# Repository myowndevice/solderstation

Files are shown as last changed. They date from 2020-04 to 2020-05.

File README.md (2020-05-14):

## Цифровая паяльная станция

Паяльная станция - специальный прибор для автоматической регулировки температуры жала обычного паяльника на 220в или для управления паяльным термофеном.
Полностью цифровой вариант.
Для измерения термопары используется самый современный метод - внешний 18-ти битный сигма-дельта ADC. Для управления вентилятором фена - ШИМ модуляция и MOSFET. PID регулятор температуры с возможностью различных настроек для фена и паяльника.

Ключевые особенности самодельной паяльной станции:
- Компактный размер
- Встроенный блок питания на 220В
- Возможность определения вида нагревателя (2 прибора, паяльник и фен)
- Цифровая регулировка мощности нагревателя на основе PID регулятора
- Возможность управления паяльником постоянного напряжения до 24В
- Возможность управления вентилятором термофена (4 скорости)
- Управление нагрузкой целыми полуволнами, с учётом перехода через 0 (меньше помех)
- Защита от перегрева нагревателя
- Индикатор температуры и скорости вентилятора
- Управление тактовыми кнопками
- Защита от ложных срабатываний управляющего симистора с помощью снаббера
- Максимальный ток нагрузки 3 А, что составляет 600 вт без радиатора.

Данный репозитарий содержит все необходимые файлы для сборки цифровой паяльной станции. Если вы будете скачивать файлы через web не забудьте скачать общую папку Kicadlib.

Ознакомится со схемой и подробным описанием данного прибора, программы, и порядка сборки можно, [прочитав эту подробную статью](http://myowndevice.ru/index.php/pribory/item/19-payalnaya-stantsiya)

Также [здесь](http://myowndevice.ru) вы найдете подробное описание как сделать другие приборы, много теории о том, как их делать, методику изготовления печатных плат и много другого.

Изучай микроконтроллеры, разрабатывай и делай электронику дома сам!

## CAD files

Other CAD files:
solderstation/Project/STM8S_StdPeriph_Template/STVD/Cosmic/stm8s003_Programmer/stm8s003_STVP.stp
solderstation/Project/STM8S_StdPeriph_Template/STVD/Cosmic/stm8s005.stp
solderstation/Project/STM8S_StdPeriph_Template/STVD/Raisonance/stm8s003.stp
solderstation/Project/STM8S_StdPeriph_Template/STVD/Cosmic/stm8s103.stp
solderstation/Project/STM8S_StdPeriph_Template/STVD/Raisonance/stm8s207.stp
solderstation/Project/STM8S_StdPeriph_Template/STVD/Cosmic/stm8s208.stp
solderstation/Project/STM8S_StdPeriph_Template/STVD/Raisonance/stm8s005.stp
solderstation/Project/STM8S_StdPeriph_Template/STVD/Cosmic/stm8s105.stp
solderstation/Project/STM8S_StdPeriph_Template/STVD/Raisonance/stm8af626x.stp
solderstation/Project/STM8S_StdPeriph_Template/STVD/Cosmic/stm8s903.stp
solderstation/Project/STM8S_StdPeriph_Template/STVD/Raisonance/stm8s208.stp
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

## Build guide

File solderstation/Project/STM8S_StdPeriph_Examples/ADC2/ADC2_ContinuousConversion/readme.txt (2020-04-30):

/** @page ADC2_ContinuousConversion Displaying the ADC2 conversion result using LEDs
  @verbatim
  ******************** (C)COPYRIGHT 2014 STMicroelectronics *******************
  * @file    ADC2/ADC2_ContinuousConversion/readme.txt
  * @author  MCD Application Team
  * @version V2.2.0
  * @date    30-September-2014
  * @brief   This file contains the description of ADC2 Continuous Conversion example.
  ******************************************************************************
  *
  * Licensed under MCD-ST Liberty SW License Agreement V2, (the "License");
  * You may not use this file except in compliance with the License.
  * You may obtain a copy of the License at:
  *
  *        http://www.st.com/software_license_agreement_liberty_v2
  *
  * Unless required by applicable law or agreed to in writing, software 
  * distributed under the License is distributed on an "AS IS" BASIS, 
  * WITHOUT WARRANTIES OR CONDITIONS OF ANY KIND, either express or implied.
  * See the License for the specific language governing permissions and
  * limitations under the License.
  *
  ******************************************************************************
  @endverbatim

  @par Example description
 
  This example provides a short description of how to use the ADC peripheral
  to convert ADC2 Channel 9 input voltage in Continuous conversion mode with interrupt.
  
  In the STM8/128-EVAL board, ADC2 Channel 9 is connected to RV1 Adjuster. 
  Turning RV1 adjuster provides a voltage which can vary from 0 Volt to 5 Volt.
  Depending on the voltage range, LEDs from 1 to 4 light up. 

  @par Directory contents

  - ADC2\ADC2_ContinuousConversion\main.c            Main file containing the "main" function
  - ADC2\ADC2_ContinuousConversion\stm8s_conf.h      Library Configuration file
  - ADC2\ADC2_ContinuousConversion\stm8s_it.c        Interrupt routines source
  - ADC2\ADC2_ContinuousConversion\stm8s_it.h        Interrupt routines declaration

  @par Hardware and Software environment

  - This example runs on STM8S and STM8A high density devices.
  
  - This example has been tested with STMicroelectronics STM8/128-EVAL evaluation 
    board and can be easily tailored to any other development board.

  - STM8/128-EVAL Set-up
     - RV1 adjuster
     - LD1..LD4

  @par How to use it ?

  In order to make the program work, you must do the following :

  - Copy all source files from this example folder to the template folder under
    Project\Template
  - Open your preferred toolchain 
  - Rebuild all files and load your image into target memory
  - Run the example
  - Turn the potentiometer RV1 on the board to change the voltage to be converted
  - The four LEDs (LD1, LD2, LD3 and LD4) follow the ADC2 value

  @note
  - High-Density STM8A devices are the STM8AF52xx STM8AF6269/8x/Ax,
    STM8AF51xx, and STM8AF6169/7x/8x/9x/Ax microcontrollers where the Flash memory
    density ranges between 32 to 128 Kbytes
  - Medium-Density STM8A devices are the STM8AF622x/4x, STM8AF6266/68,
    STM8AF612x/4x, and STM8AF6166/68 microcontrollers where the Flash memory 
    density ranges between 8 to 32 Kbytes
  - High-Density STM8S devices are the STM8S207xx, STM8S007 and STM8S208xx microcontrollers
    where the Flash memory density ranges between 32 to 128 Kbytes.
  - Medium-Density STM8S devices are the STM8S105x and STM8S005 microcontrollers
    where the Flash memory density ranges between 16 to 32-Kbytes.
  - Low-Density STM8S devices are the STM8S103xx, STM8S003 and STM8S903xx microcontrollers
    where the Flash density is 8 Kbytes.
   
 * <h3><center>&copy; COPYRIGHT STMicroelectronics</center></h3>
 */

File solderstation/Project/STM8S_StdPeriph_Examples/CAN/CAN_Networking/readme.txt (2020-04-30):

/** @page Networking  Networking with CAN to control Leds
  @verbatim
  ******************** (C)COPYRIGHT 2014 STMicroelectronics *******************
  * @file    CAN/CAN_Networking/readme.txt
  * @author  MCD Application Team
  * @version V2.2.0
  * @date    30-September-2014
  * @brief   This file contains the main function for CAN networking example.
  ******************************************************************************
  *
  * Licensed under MCD-ST Liberty SW License Agreement V2, (the "License");
  * You may not use this file except in compliance with the License.
  * You may obtain a copy of the License at:
  *
  *        http://www.st.com/software_license_agreement_liberty_v2
  *
  * Unless required by applicable law or agreed to in writing, software 
  * distributed under the License is distributed on an "AS IS" BASIS, 
  * WITHOUT WARRANTIES OR CONDITIONS OF ANY KIND, either express or implied.
  * See the License for the specific language governing permissions and
  * limitations under the License.
  *
  ******************************************************************************
  @endverbatim
  
  @par Example description

  This example provides a short description of how to use the CAN peripheral:
  CAN peripheral is configured to send and receive CAN frames. 
  The sent frames  are used to control Leds.
  An LCD is used to give information about : 
   - CAN sender (sender of the frame)
   - CAN receiver (receiver of the frame)
   - Controlled Led (set ON)

  The CAN serial communication link is a bus to which a number of units may be
  connected. This number has no theoretical limit. Practically the total number
  of units will be limited by delay times and/or electrical loads on the bus line.

  @note This example is tested with a bus of 3 units. The same program example 
  is loaded in all units to send and receive frames.

  CAN is configured as follow:
    - Bit Rate   = 1 Mbit/s  
    - CAN Clock  = Internal (HSI)
    - ID Filter = All identifiers are allowed
    - RTR = Data
    - DLC = 1 byte

  @par Directory contents

  - CAN\CAN_Networking\main.c             Main file containing the "main" function
  - CAN\CAN_Networking\main.h             Main file declaration
  - CAN\CAN_Networking\stm8s_conf.h       Library Configuration file
  - CAN\CAN_Networking\stm8s_it.c         Interrupt routines source 
  - CAN\CAN_Networking\stm8s_it.h         Interrupt routines declaration

  @par Hardware environment

  - This example runs only on STM8S208 and STM8A52Ax devices.
  
  - This example has been tested with STMicroelectronics STM8/128-EVAL evaluation 
    board and can be easily tailored to any other development board.

  - STM8/128-EVAL Set-up
     - Key push button
     - LD1..LD4
     - Mono LCD

  - If another board is used, consider the folloing hardware connections :
      - PH3 -> LED1 -> resistor -> ground
      - PH2 -> LED2 -> resistor -> ground
      - PH1 -> LED3 -> resistor -> ground
      - PH0 -> LED4 -> resistor -> ground
      - PC0 -> Key Button -> ground + pull-up on 5V
      - PG1 (CAN Rx) and PG0 (CAN Tx) connected to a DB9 connector using a CAN Bus
        transceiver (eg. L9616).

  - Connect a female/female CAN cable between at least 2 EVAL CAN connectors
  (CN8 on STM8/128-EVAL board) 
    - Connector 1 DB9_PIN2 to Connector 2 DB9_PIN2  (CAN_L)
    - Connector 1 DB9_PIN5 to Connector 2 DB9_PIN5  ( GND )
    - Connector 1 DB9_PIN7 to Connector 2 DB9_PIN7  (CAN_H)

  @par How to use it ?

  In order to make the program work, you must do the following :

  - Copy all source files from this example folder to the template folder under
    Project\Template
  - Open your preferred toolchain 
  - Add the required file:
    - stm8s_eval_lcd.c  (under Utilities\STM8S_EVAL\Common)
  - Rebuild all files and load your image into target memory
  - Run the example
  - In the first time the LCD shows the message "STM8S CAN  Press Key".
  - (1) By Pressing on Key Button : CAN send a Frame to command LED1 (LD1 ON)
    on the N eval-boards connected to the bus, all other Leds are OFF. 
    The sender LCD shows "STM8S CAN  Sender  LD1 ON".
    The N-1 receivers LCD shows "STM8S CAN  Receiver  LD1 ON".
  - Press on Key Button again to send CAN Frame to command LD2 ON on the N eval-boards,
    all other Leds are OFF.
    The sender LCD shows "STM8S CAN  Sender  LD2 ON".
    The N-1 receivers LCD shows "STM8S CAN  Receiver  LD2 ON".
  - Press on Key Button again to send CAN Frame to command LD3 ON on the N eval-boards,
    all other Leds are OFF.
    The sender LCD shows "STM8S CAN  Sender  LD3 ON".
    The N-1 receivers LCD shows "STM8S CAN  Receiver  LD3 ON".
  - Press on Key Button again to send CAN Frame to command LD4 ON on the N eval-boards,
    all other Leds are OFF.
    The sender LCD shows "STM8S CAN  Sender  LD4 ON".
    The N-1 receivers LCD shows "STM8S CAN  Receiver  LD4 ON".
  - Press on Key Button again to go to step (1)
  @note Any unit in the CAN bus may play the role of sender (by pressing on the
        key) or receiver.

  @note
  - High-Density STM8A devices are the STM8AF52xx STM8AF6269/8x/Ax,
    STM8AF51xx, and STM8AF6169/7x/8x/9x/Ax microcontrollers where the Flash memory
    density ranges between 32 to 128 Kbytes
  - Medium-Density STM8A devices are the STM8AF622x/4x, STM8AF6266/68,
    STM8AF612x/4x, and STM8AF6166/68 microcontrollers where the Flash memory 
    density ranges between 8 to 32 Kbytes
  - High-Density STM8S devices are the STM8S207xx, STM8S007 and STM8S208xx microcontrollers
    where the Flash memory density ranges between 32 to 128 Kbytes.
  - Medium-Density STM8S devices are the STM8S105x and STM8S005 microcontrollers
    where the Flash memory density ranges between 16 to 32-Kbytes.
  - Low-Density STM8S devices are the STM8S103xx, STM8S003 and STM8S903xx microcontrollers
    where the Flash density is 8 Kbytes.
      
 * <h3><center>&copy; COPYRIGHT STMicroelectronics</center></h3>
 */

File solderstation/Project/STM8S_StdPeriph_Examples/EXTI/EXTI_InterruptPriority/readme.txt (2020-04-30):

/** @page EXTI_InterruptPriority Reading buttons state using external interrupts
  @verbatim
  ******************** (C)COPYRIGHT 2014 STMicroelectronics *******************
  * @file    EXTI/EXTI_InterruptPriority/readme.txt
  * @author  MCD Application Team
  * @version V2.2.0
  * @date    30-September-2014
  * @brief   This file contains the description of EXTI priority example.
  ******************************************************************************
  *
  * Licensed under MCD-ST Liberty SW License Agreement V2, (the "License");
  * You may not use this file except in compliance with the License.
  * You may obtain a copy of the License at:
  *
  *        http://www.st.com/software_license_agreement_liberty_v2
  *
  * Unless required by applicable law or agreed to in writing, software 
  * distributed under the License is distributed on an "AS IS" BASIS, 
  * WITHOUT WARRANTIES OR CONDITIONS OF ANY KIND, either express or implied.
  * See the License for the specific language governing permissions and
  * limitations under the License.
  *
  ******************************************************************************
  @endverbatim

  @par Example description

  This example provides a short description of how to use the EXTI peripheral:
  - Configuration of External Interrupt / Falling edge and TLI
  - LEDs are toggling at each interrupt detection

  @par Directory contents

  - EXTI\EXTI_InterruptPriority\main.c             Main file containing the "main" function
  - EXTI\EXTI_InterruptPriority\main.h             Main file containing the "main" header function
  - EXTI\EXTI_InterruptPriority\stm8s_conf.h       Library Configuration file
  - EXTI\EXTI_InterruptPriority\stm8s_it.c         Interrupt routines source
  - EXTI\EXTI_InterruptPriority\stm8s_it.h         Interrupt routines declaration

 @par Hardware and Software environment

  - This example runs on STM8S and STM8A High density, Medium density and Low 
    density devices.
  
  - This example has been tested with STMicroelectronics STM8/128-EVAL evaluation 
    board and can be easily tailored to any other development board.

  - STM8/128-EVAL Set-up
     - Four leds LD1 to LD4 are used.
     - Joystick LEFT, RIGHT, UP, DOWN and SEL buttons are used.

  @par How to use it ?

  In order to make the program work, you must do the following :

  - Copy all source files from this example folder to the template folder under
    Project\Template
  - Open your preferred toolchain 
  - Rebuild all files and load your image into target memory
  - Run the example
  - The LD1, LD2, LD3 and LD4 are ON per default
  - Joystick LEFT  pressed: toggle LED1
  - Joystick RIGHT pressed: toggle LED2
  - Joystick UP    pressed: toggle LED3
  - Joystick DOWN  pressed: toggle LED4
  - Joystick SEL   pressed: toggle all LEDs

  @note
  - High-Density STM8A devices are the STM8AF52xx STM8AF6269/8x/Ax,
    STM8AF51xx, and STM8AF6169/7x/8x/9x/Ax microcontrollers where the Flash memory
    density ranges between 32 to 128 Kbytes
  - Medium-Density STM8A devices are the STM8AF622x/4x, STM8AF6266/68,
    STM8AF612x/4x, and STM8AF6166/68 microcontrollers where the Flash memory 
    density ranges between 8 to 32 Kbytes
  - High-Density STM8S devices are the STM8S207xx, STM8S007 and STM8S208xx microcontrollers
    where the Flash memory density ranges between 32 to 128 Kbytes.
  - Medium-Density STM8S devices are the STM8S105x and STM8S005 microcontrollers
    where the Flash memory density ranges between 16 to 32-Kbytes.
  - Low-Density STM8S devices are the STM8S103xx, STM8S003 and STM8S903xx microcontrollers
    where the Flash density is 8 Kbytes.
      
 * <h3><center>&copy; COPYRIGHT STMicroelectronics</center></h3>
 */

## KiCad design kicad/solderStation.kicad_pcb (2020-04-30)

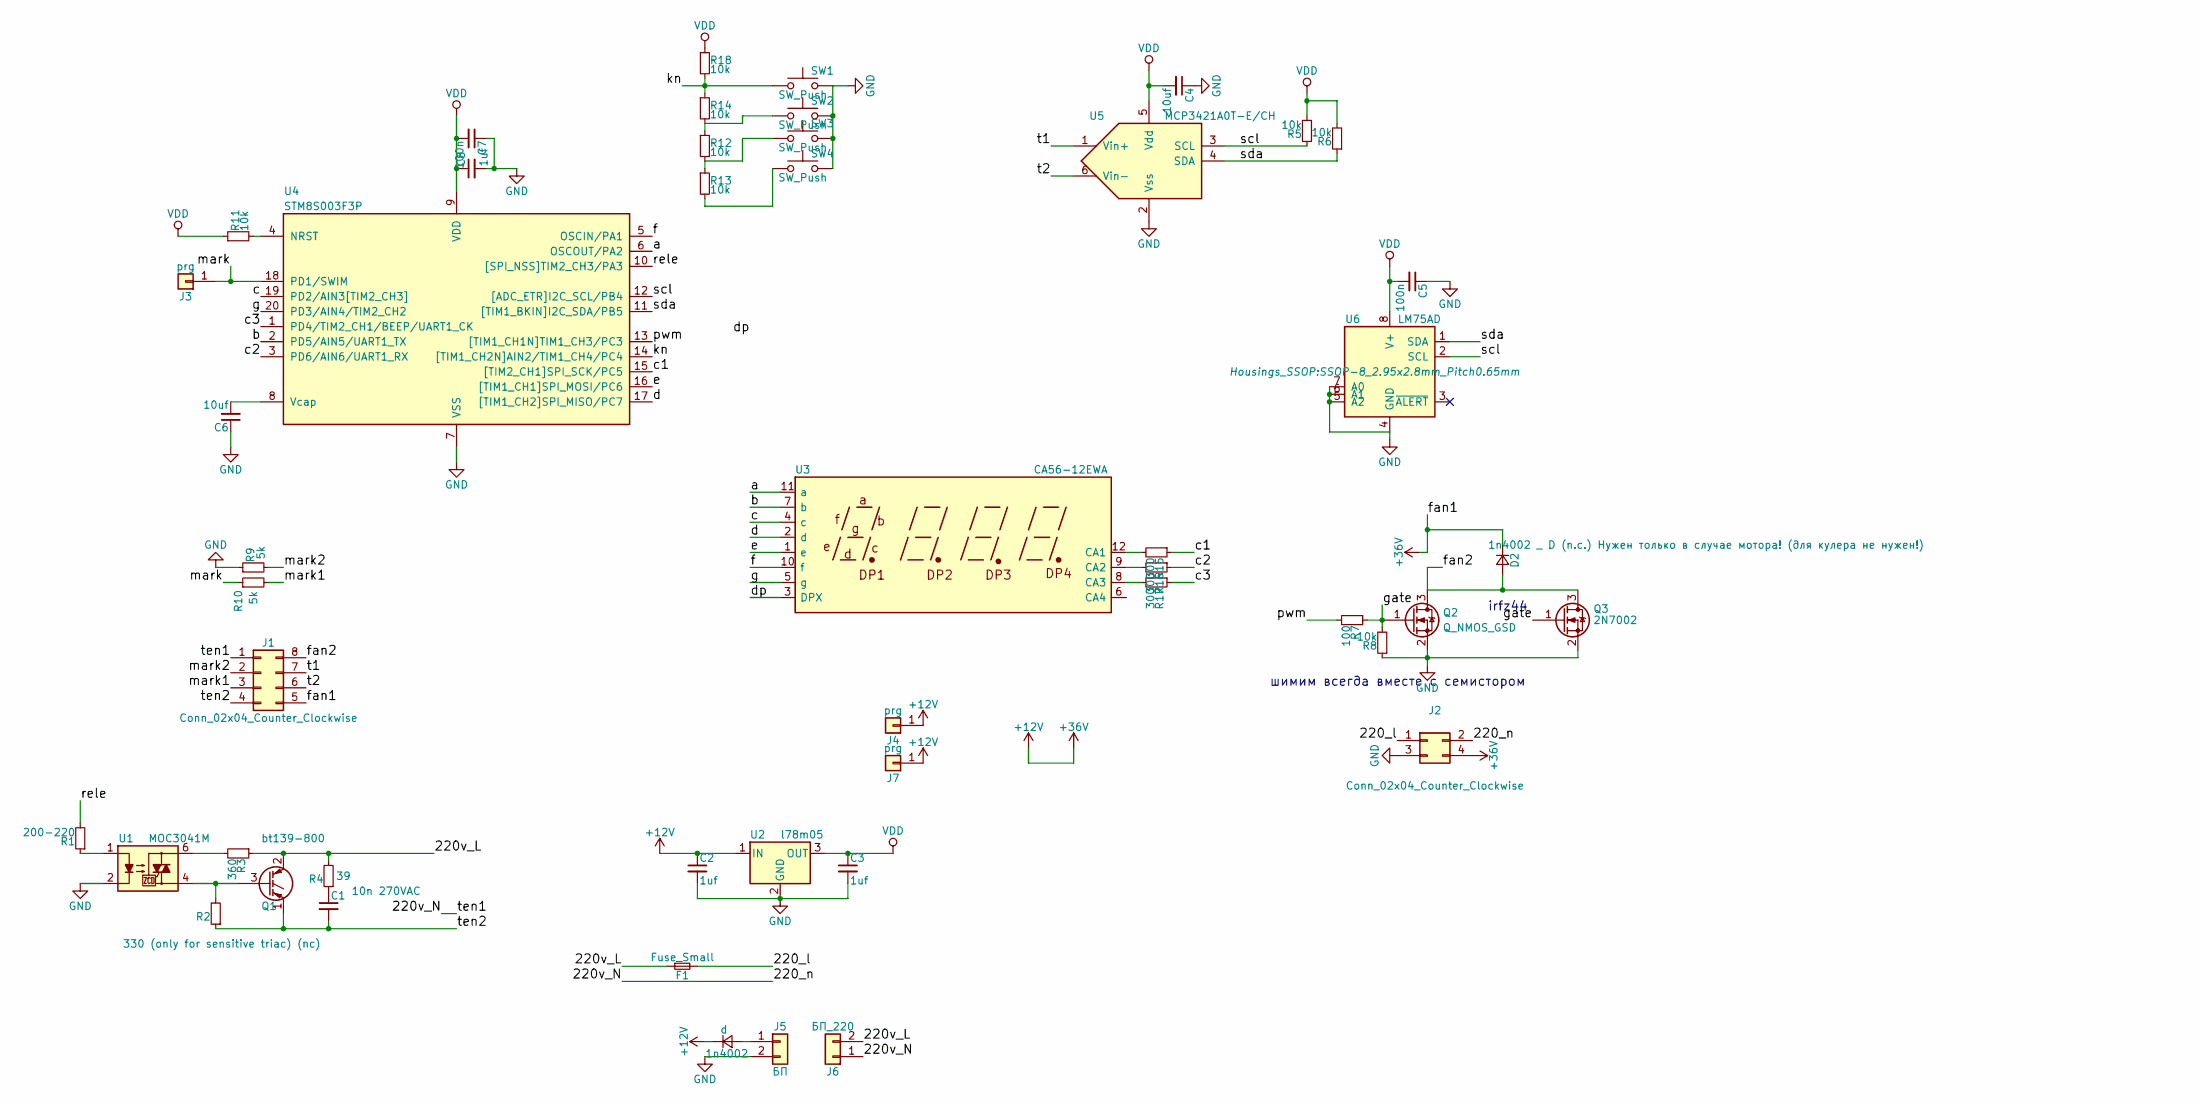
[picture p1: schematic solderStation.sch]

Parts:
C1: 10n 270VAC; C_Rect_L13.0mm_W5.0mm_P10.00mm_FKS3_FKP3_MKS4
C2, C3, C8: 1uf; C_0805_HandSoldering
C4, C6: 10uf; C_0805_HandSoldering
C5, C7: 100n; C_0603_HandSoldering
D2: 1n4002 _ D (n.c.) Нужен только в случае мотора! (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; D_MiniMELF
F1: Fuse_Small; Fuseholder5x20_horiz_open_inline_Type-I
J1: Conn_02x04_Counter_Clockwise; Molex_MiniFit-JR-5569-08A2_2x04x4.20mm_Angled
J2: Conn_02x04_Counter_Clockwise; Molex_MiniFit-JR-5569-04A2_2x02x4.20mm_Angled
J3: prg; wirepad_mini
J4, J7: prg; wirepadme
J5: БП; Pin_Header_Straight_1x02_Pitch2.54mm
J6: БП_220; Pin_Header_Straight_1x02_Pitch2.54mm
Q1: bt139-800; TO-220-3_Horizontal_Reversed
Q2: Q_NMOS_GSD; TO-252-2
Q3: 2N7002; SOT-23
R1: 200-220; R_0603_HandSoldering
R2: 330 (only for sensitive triac) (nc); R_Axial_DIN0207_L6.3mm_D2.5mm_P10.16mm_Horizontal
R3: 360; R_Axial_DIN0207_L6.3mm_D2.5mm_P10.16mm_Horizontal
R4: 39; R_Axial_DIN0207_L6.3mm_D2.5mm_P10.16mm_Horizontal
R5, R6, R8, R11, R12, R13, R14, R18: 10k; R_0603_HandSoldering
R7: 100; R_0603_HandSoldering
R9, R10: 5k; R_0603_HandSoldering
R15, R16, R17: 300; R_0603_HandSoldering
SW1, SW2, SW3, SW4: SW_Push; SW_PUSH_6mm
U1: MOC3041M; DIP-6_W7.62mm_LongPads
U2: l78m05; TO-252-2_Rectifier
U3: CA56-12EWA; indicator_3cif
U4: STM8S003F3P; TSSOP-20_4.4x6.5mm_Pitch0.65mm
U5: MCP3421A0T-E/CH; SOT-23-6_Handsoldering
U6: LM75AD; SSOP-8_2.95x2.8mm_Pitch0.65mm
d: 1n4002; D_MiniMELF

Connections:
+12V: C2.1, D2.1 (K), J1.5, J2.4, J4.1, J7.1, U2.1 (IN), d.1 (K); also elsewhere on the board
/220_l: F1.2, J2.1
/220_n: J1.1, J2.2, J6.1
/220v_L: F1.1, J6.2, Q1.2 (C), R3.1, R4.2
/a: U3.11 (a), U4.6 (OSCOUT/PA2)
/b: U3.7 (b), U4.2 (PD5/AIN5/UART1_TX)
/c: U3.4 (c), U4.19 (PD2/AIN3[TIM2_CH3])
/c1: R15.1, U4.15 ([TIM2_CH1]SPI_SCK/PC5)
/c2: R16.1, U4.3 (PD6/AIN6/UART1_RX)
/c3: R17.1, U4.1 (PD4/TIM2_CH1/BEEP/UART1_CK)
/d: U3.2 (d), U4.17 ([TIM1_CH2]SPI_MISO/PC7)
/e: U3.1 (e), U4.16 ([TIM1_CH1]SPI_MOSI/PC6)
/f: U3.10 (f), U4.5 (OSCIN/PA1)
/fan2: D2.2 (A), J1.8, Q2.3 (D), Q3.3 (D)
/g: U3.5 (g), U4.20 (PD3/AIN4/TIM2_CH2)
/gate: Q2.1 (G), Q3.1 (G), R7.1, R8.2
/kn: R14.1, R18.2, SW1.1, U4.14 ([TIM1_CH2N]AIN2/TIM1_CH4/PC4)
/mark: J3.1, R10.1, U4.18 (PD1/SWIM)
/mark1: J1.3, R10.2
/mark2: J1.2, R9.2
/pwm: R7.2, U4.13 ([TIM1_CH1N]TIM1_CH3/PC3)
/rele: R1.2, U4.10 ([SPI_NSS]TIM2_CH3/PA3)
/scl: R5.1, U4.12 ([ADC_ETR]I2C_SCL/PB4), U5.3 (SCL), U6.2 (SCL)
/sda: R6.1, U4.11 ([TIM1_BKIN]I2C_SDA/PB5), U5.4 (SDA), U6.1 (SDA)
/t1: J1.7, U5.1 (Vin+)
/t2: J1.6, U5.6 (Vin-)
/ten2: C1.2, J1.4, Q1.1 (E), R2.1
GND: C2.2, C3.2, C4.1, C5.1, C6.1, C7.1, C8.2, J2.3, J5.2, Q2.2 (S), Q3.2 (S), R8.1, R9.1, SW1.2, SW2.2, SW3.2, SW4.2, U1.2, U2.2 (GND), U4.7 (VSS), U5.2 (Vss), U6.4 (GND), U6.5 (A2), U6.6 (A1), U6.7 (A0)
unnamed: C1.1, R4.1
unnamed: C6.2, U4.8 (Vcap)
unnamed 30: J5.1, d.2 (A); also elsewhere on the board
unnamed: Q1.3 (G), R2.2, U1.4
unnamed: R1.1, U1.1
unnamed: R3.2, U1.6
unnamed: R11.2, U4.4 (NRST)
unnamed: R12.1, R14.2, SW2.1
unnamed: R12.2, R13.1, SW3.1
unnamed: R13.2, SW4.1
unnamed: R15.2, U3.12 (CA1)
unnamed: R16.2, U3.9 (CA2)
unnamed: R17.2, U3.8 (CA3)
VDD: C3.1, C4.2, C5.2, C7.2, C8.1, R5.2, R6.2, R11.1, R18.1, U2.3 (OUT), U4.9 (VDD), U5.5 (Vdd), U6.8 (V+)

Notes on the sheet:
irfz44
шимим всегда вместе с семистором

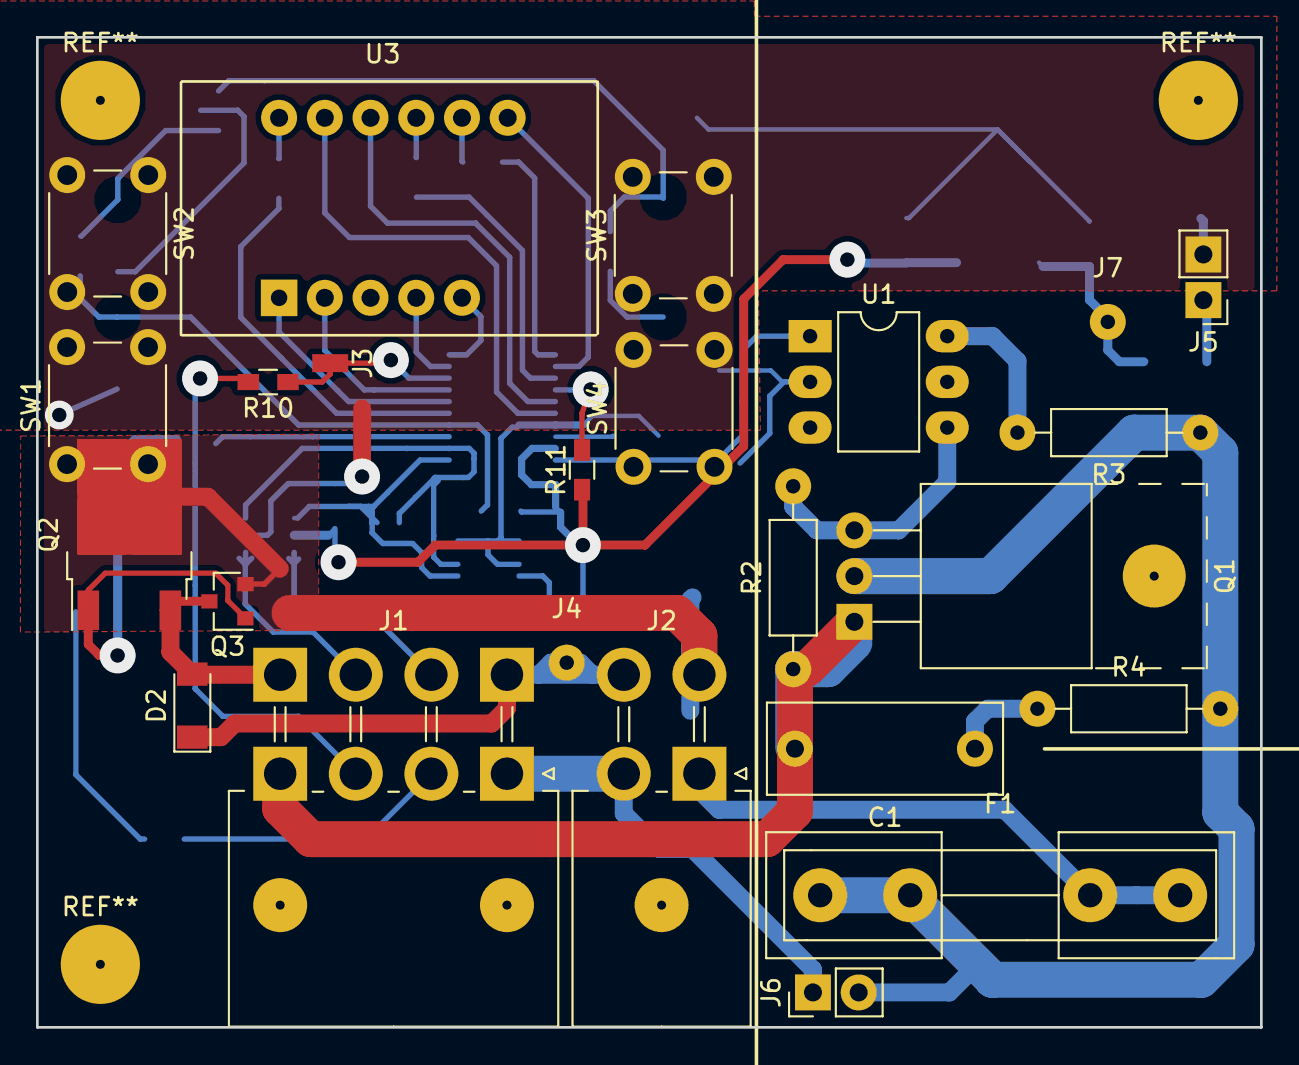
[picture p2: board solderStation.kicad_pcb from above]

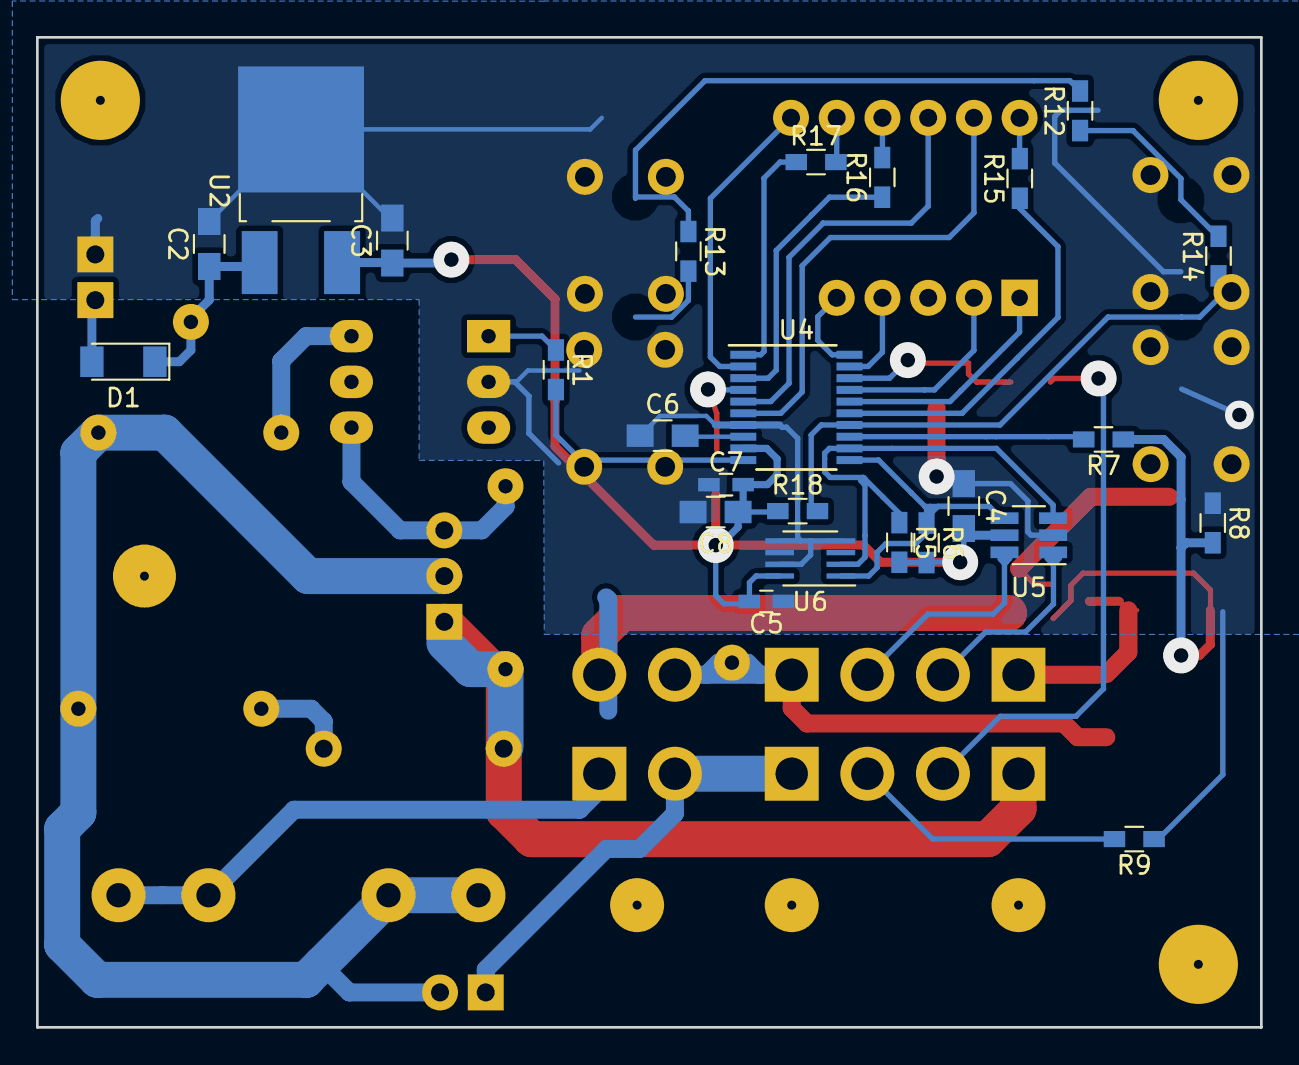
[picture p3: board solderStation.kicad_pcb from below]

Board: 2 copper layers, 68.0 x 55.0 mm, 49 parts (25 on the bottom side), 42 nets.

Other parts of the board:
D1: D_Small; D_MiniMELF

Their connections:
+12V: D1.1; also elsewhere on the board
unnamed 30: D1.2; also elsewhere on the board

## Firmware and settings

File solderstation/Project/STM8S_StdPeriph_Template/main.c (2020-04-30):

/**
  ******************************************************************************
  * @file    Project/main.c 
  * @author  MCD Application Team
  * @version V2.2.0
  * @date    30-September-2014
  * @brief   Main program body
   ******************************************************************************
  * @attention
  *
  * <h2><center>&copy; COPYRIGHT 2014 STMicroelectronics</center></h2>
  *
  * Licensed under MCD-ST Liberty SW License Agreement V2, (the "License");
  * You may not use this file except in compliance with the License.
  * You may obtain a copy of the License at:
  *
  *        http://www.st.com/software_license_agreement_liberty_v2
  *
  * Unless required by applicable law or agreed to in writing, software 
  * distributed under the License is distributed on an "AS IS" BASIS, 
  * WITHOUT WARRANTIES OR CONDITIONS OF ANY KIND, either express or implied.
  * See the License for the specific language governing permissions and
  * limitations under the License.
  *
  ******************************************************************************
  */ 


/* Includes ------------------------------------------------------------------*/
#include "stm8s.h"

//time
u8 ind[3]={0,0,0};
u8 tchk[3]={0,0,0};
u8 numind=0;


#define KNNUM  4  //колво кнопок
#define KNONE  4  //обычное нажатие
#define KNLONG 5  //долгое
#define KNTWO  6  //двойного нет!

#define KNDTIME 50 //время в мс дребезга контактов
#define KNTIMETWO 300 //время в мс двойного нажатия
#define KNTIMELONG 1000 //время в мс долгого нажатия

//паяльная станция
u8 fan=1;//1 - фен, 0 - паяльник
u8 fanold=0;
u8 speedfan=3;//1-2-3-4
u8 speedfanold=0;//1-2-3-4
u16 temp=0;//заданная температура
u16 tempold=0;
u8 timeshownext=0;
u8 showind=0;
u8 spiralpower=0;
u8 spiralon=0;
u16 spiraltime=0;
#define MAXPWM 5

//пид регулятор
#define hKp_Divisor 512
#define hKi_Divisor 2000
s32 wIntegral=0;

#define hUpper_Limit_Output (s32)70
#define wUpper_Limit_Integral (s32)(hUpper_Limit_Output*hKi_Divisor)

#define hLower_Limit_Output (s32)0
#define wLower_Limit_Integral (s32)(hLower_Limit_Output * hKi_Divisor)


s16 hKp_Gain=230;
s16 hKi_Gain=20;//50;

//пид регулятор

u16 adcval;
			
u8  kn[KNNUM];//итоговое состояние кнопки 0 - не обработана, и дальше обычное нажатие долгое и двойное
u8  knstatus[KNNUM];//состояние кнопки 0 - не нажата 1 - нажата
u16 kntime[KNNUM];//время нажатия кнопки
u8  kndtime=0;

u16 timenct=0;
u16 timemcp=0;
u8 timeuv=0;

u8 rezhim=0;

u8 sec,min;

void Delay (u16 nCount);
uint32_t LSIMeasurment(void);

uint32_t current_millis = 0;
bool blueen;
uint8_t buff[30];

#define MCPaddr 0b01101000
#define UVaddr  (0x10)
#define NCTaddr  (0x48)

int kn1=0,kn2=0,kn1old=0,kn2old=0,fandes=0;fansot=0;

//сегменты индикатора!

#define ON1 GPIO_WriteHigh(GPIOC,GPIO_PIN_5)
#define ON2 GPIO_WriteHigh(GPIOD,GPIO_PIN_6)
#define ON3 GPIO_WriteHigh(GPIOD,GPIO_PIN_4)
#define OFF1 GPIO_WriteLow(GPIOC,GPIO_PIN_5)
#define OFF2 GPIO_WriteLow(GPIOD,GPIO_PIN_6)
#define OFF3 GPIO_WriteLow(GPIOD,GPIO_PIN_4)

#define AON GPIO_WriteLow(GPIOA,GPIO_PIN_2)
#define BON GPIO_WriteLow(GPIOD,GPIO_PIN_5)
#define CON GPIO_WriteLow(GPIOD,GPIO_PIN_2)
#define DON GPIO_WriteLow(GPIOC,GPIO_PIN_7)
#define EON GPIO_WriteLow(GPIOC,GPIO_PIN_6)
#define FON GPIO_WriteLow(GPIOA,GPIO_PIN_1)
#define GON GPIO_WriteLow(GPIOD,GPIO_PIN_3)
#define TON ;//GPIO_WriteLow(GPIOC,GPIO_PIN_5)


#define ALLOFF GPIO_WriteHigh(GPIOC,GPIO_PIN_6|GPIO_PIN_7);GPIO_WriteHigh(GPIOD,GPIO_PIN_2|GPIO_PIN_3|GPIO_PIN_5);GPIO_WriteHigh(GPIOA,GPIO_PIN_1|GPIO_PIN_2);
//GPIO_WriteLow(GPIOC,GPIO_PIN_5);GPIO_WriteLow(GPIOD,GPIO_PIN_6|GPIO_PIN_4);


const double cK[9]={
2.508355*10,
7.860106/100,
-2.503131/10,
8.315270/100,
-1.228034/100,
9.804036/10000,
-4.413030/100000,
1.057734/1000/1000,
-1.052755/10000/10000};

const double cKm[8]={
2.5173462*10,
-1.1662878,
-1.0833638,
-8.9773540/10,
-3.7342377/10,
-8.6632643/100,
-1.0450598/100,
-5.1920577/100/100};

const double cKf[7]={
-1.318058*100,
4.830222*10,
-1.646031,
5.464731/100,
-9.650715/10000,
8.802193/1000000,
-3.110810/100000000};

long mcpT,bmeT;

s16 PI_Regulator(s16 hReference, s16 hPresentFeedback)
{
  s32 wError, wProportional_Term,wIntegral_Term, houtput_32;
  s32 wIntegral_sum_temp; 
    
  // error computation
  wError= (s32)(hReference - hPresentFeedback);
 
  // Proportional term computation
  wProportional_Term = hKp_Gain * wError;

  // Integral term compuztation
  if (hKi_Gain == 0)
  {
    wIntegral = 0;
  }
  else
  { 
    wIntegral_Term = hKi_Gain * wError;
    wIntegral_sum_temp = wIntegral + wIntegral_Term;
		
		if (wIntegral_sum_temp > 0)
		{
			if (wIntegral < 0)
			{
				if (wIntegral_Term < 0)
				{
					wIntegral_sum_temp = S32_MIN;
				}
			}
		}
		else
		{
			if (wIntegral > 0)
			{
				if (wIntegral_Term > 0)
				{
					wIntegral_sum_temp = S32_MAX;
				}
			}
		}		
    
    if (wIntegral_sum_temp > wUpper_Limit_Integral)
    {
      wIntegral = wUpper_Limit_Integral;
    }
    else if (wIntegral_sum_temp < wLower_Limit_Integral)
    { 
      wIntegral = wLower_Limit_Integral;
    }
    else
    {
      wIntegral = wIntegral_sum_temp;
    }
  }
  
  houtput_32 = (wProportional_Term/hKp_Divisor+wIntegral/hKi_Divisor);

  if (houtput_32 > hUpper_Limit_Output)
  {
    houtput_32 = hUpper_Limit_Output;		  			 	
  }
  else if (houtput_32 < hLower_Limit_Output)
  {
    houtput_32 = hLower_Limit_Output;
  }
  return((s16)(houtput_32)); 		
}



char* shift_and_mul_utoa16(uint16_t n, char *buffer)
{
    char *ptr;
		uint8_t d4, d3, d2, d1, q, d0;

        d1 = (n>>4)  & 0xF;
        d2 = (n>>8)  & 0xF;
        d3 = (n>>12) & 0xF;

        d0 = 6*(d3 + d2 + d1) + (n & 0xF);
        q = (d0 * 0xCD) >> 11;
        d0 = d0 - 10*q;

        d1 = q + 9*d3 + 5*d2 + d1;
        q = (d1 * 0xCD) >> 11;
        d1 = d1 - 10*q;

        d2 = q + 2*d2;
        q = (d2 * 0x1A) >> 8;
        d2 = d2 - 10*q;

        d3 = q + 4*d3;
        d4 = (d3 * 0x1A) >> 8;
        d3 = d3 - 10*d4;

				ptr = buffer;
    *ptr++ = ( d4 + '0' );
    *ptr++ = ( d3 + '0' );
    *ptr++ = ( d2 + '0' );
    *ptr++ = ( d1 + '0' );
    *ptr++ = ( d0 + '0' );
        *ptr = 0;

        while(buffer[0] == '0') ++buffer;
        return buffer;
}


int I2C_writenbyte(uint8_t addr, uint8_t* buff, int nbyte, int nostop)
{
	uint32_t timeout;
	timeout = current_millis + 1000;
	
	while (I2C_GetFlagStatus(I2C_FLAG_BUSBUSY))
	{	
		if (current_millis>timeout) return 0;
	}	
	
	I2C->CR2 |= I2C_CR2_START;//I2C_GenerateSTART(ENABLE);
	while (!I2C_CheckEvent(I2C_EVENT_MASTER_MODE_SELECT))
	{	
		if (current_millis>timeout) return 0;
	}	
			
  I2C_Send7bitAddress((uint8_t)addr << 1, I2C_DIRECTION_TX);
	while (!I2C_CheckEvent(I2C_EVENT_MASTER_TRANSMITTER_MODE_SELECTED))
	{	
		if (current_millis>timeout) return 0;
	}	
	
	while (nbyte>0)
	{
		I2C->DR = (uint8_t)*buff;//I2C_SendData((uint8_t)*buff);//ctrl meas
		while(!I2C_GetFlagStatus( I2C_FLAG_TRANSFERFINISHED))
		{	
			if (current_millis>timeout) return 0;
		}	
		*buff++;
		nbyte--;
	}
	
	if(nostop==0) 
	{
		I2C->CR2 |= I2C_CR2_STOP;//I2C_GenerateSTOP(ENABLE);
	}
	
	return 1;
}

int I2C_readnbyte(uint8_t addr, uint8_t * buff, int nbyte,int nocheckbusy)
{
	uint32_t timeout;
	timeout = current_millis + 1000;
	
	if (nocheckbusy==0) 
	{
		while (I2C_GetFlagStatus(I2C_FLAG_BUSBUSY))
		{	
			if (current_millis>timeout) return 0;
		}
	}	
	
	I2C->CR2 |= I2C_CR2_START;//I2C_GenerateSTART(ENABLE);
	while (!I2C_CheckEvent(I2C_EVENT_MASTER_MODE_SELECT))
	{	
		if (current_millis>timeout) return 0;
	}	
	
	I2C_Send7bitAddress((uint8_t)addr << 1, I2C_DIRECTION_RX);
	
	if (nbyte >= 3) 
	{
		
		while (I2C_GetFlagStatus( I2C_FLAG_ADDRESSSENTMATCHED) == RESET)
		{	
			if (current_millis>timeout) return 0;
		}	
		disableInterrupts();
		(void)I2C->SR3;
		enableInterrupts();
	
		while  (nbyte > 3) {
			
			while (I2C_GetFlagStatus( I2C_FLAG_TRANSFERFINISHED) == RESET)
			{	
				if (current_millis>timeout) return 0;
			}	
		
			*buff = ((uint8_t)I2C->DR);//I2C_ReceiveData();
			*buff++;
			nbyte--;
		}
	
		//осталось 3 байта!
	
		while (I2C_GetFlagStatus( I2C_FLAG_TRANSFERFINISHED) == RESET)
		{	
			if (current_millis>timeout) return 0;
		}	
		
		I2C->CR2 &= (uint8_t)(~I2C_CR2_ACK);//I2C_AcknowledgeConfig(I2C_ACK_NONE);
		disableInterrupts();
		*buff = ((uint8_t)I2C->DR);//I2C_ReceiveData();
		*buff++;
		I2C->CR2 |= I2C_CR2_STOP;//I2C_GenerateSTOP(ENABLE);
		*buff = ((uint8_t)I2C->DR);//I2C_ReceiveData();
		enableInterrupts();
		*buff++;
		while (I2C_GetFlagStatus( I2C_FLAG_RXNOTEMPTY) == RESET)
		{	
			if (current_millis>timeout) return 0;
		}	
	
		*buff = ((uint8_t)I2C->DR);//I2C_ReceiveData();	
		 nbyte=0;

		while(I2C->CR2 & I2C_CR2_STOP)
    {	
			if (current_millis>timeout) return 0;
		}	
	
		
    /* Re-Enable Acknowledgement to be ready for another reception */
    I2C->CR2 |= I2C_CR2_ACK;
		I2C->CR2 &= (uint8_t)(~I2C_CR2_POS);//I2C_AcknowledgeConfig( I2C_ACK_CURR);
	
	}
	
	
	if (nbyte == 2) 
	{
		I2C_AcknowledgeConfig(I2C_ACK_NEXT);
		
		while (I2C_GetFlagStatus( I2C_FLAG_ADDRESSSENTMATCHED) == RESET)
		{	
			if (current_millis>timeout) return 0;
		}	
		(void)I2C->SR3;
		I2C_AcknowledgeConfig(I2C_ACK_NONE);
    
		while (I2C_GetFlagStatus( I2C_FLAG_TRANSFERFINISHED) == RESET)
		{	
			if (current_millis>timeout) return 0;
		}	
	
		disableInterrupts();
		I2C_GenerateSTOP(ENABLE);
		*buff= I2C_ReceiveData();
		enableInterrupts();
		// Point to the next location where the byte read will be saved
		*buff++;  
		*buff= I2C_ReceiveData();
		nbyte=0; 
		
		while(I2C->CR2 & I2C_CR2_STOP)
    {	
			if (current_millis>timeout) return 0;
		}	
	
		
    // Re-Enable Acknowledgement to be ready for another reception
    I2C_AcknowledgeConfig( I2C_ACK_CURR);
	}
	
	
	if (nbyte == 1) 
	{
		I2C->CR2 &= (uint8_t)(~I2C_CR2_ACK);//I2C_AcknowledgeConfig(I2C_ACK_NONE);   
		
		while(I2C_GetFlagStatus( I2C_FLAG_ADDRESSSENTMATCHED) == RESET)
    {	
			if (current_millis>timeout) return 0;
		}	
			
		disableInterrupts();
    
    /* Clear ADDR register by reading SR1 then SR3 register (SR1 has already been read) */
    (void)I2C->SR3;
    
    /* Send STOP Condition */
    I2C->CR2 |= I2C_CR2_STOP;//I2C_GenerateSTOP( ENABLE);
   
    /* Call User callback for critical section end (should typically re-enable interrupts) */
    enableInterrupts();
    
    /* Wait for the byte to be received */
    while(I2C_GetFlagStatus( I2C_FLAG_RXNOTEMPTY) == RESET)
    {	
			if (current_millis>timeout) return 0;
		}	
	
		
    /* Read the byte received from the EEPROM */
    *buff = ((uint8_t)I2C->DR);//I2C_ReceiveData();
    
    /* Decrement the read bytes counter */
		nbyte=0;

    /* Wait to make sure that STOP control bit has been cleared */
    while(I2C->CR2 & I2C_CR2_STOP)
    {	
			if (current_millis>timeout) return 0;
		}	
	
		
    /* Re-Enable Acknowledgement to be ready for another reception */
    I2C->CR2 |= I2C_CR2_ACK;
		I2C->CR2 &= (uint8_t)(~I2C_CR2_POS);//I2C_AcknowledgeConfig( I2C_ACK_CURR);
	}
	
	return 1;
}

int nctinit(void)
{
		
		//not need
		buff[0] = (uint8_t) 0b1;
		buff[1] = (uint8_t) 0b0;//config reg
		if( ! I2C_writenbyte((uint8_t)NCTaddr, buff, 1,0) ) 
		{
			I2C->CR2 |= I2C_CR2_STOP;//I2C_GenerateSTOP(ENABLE);
			return 0;
		};
		

		return 1;
}

int nctdata(void)
{
		long tmcpT;
		
		buff[0] = (uint8_t) 0x00;
		if( ! I2C_writenbyte((uint8_t)NCTaddr, buff, 1,0) ) 
		{
			I2C_GenerateSTOP(ENABLE);
			return 0;
		};
		
		if (! I2C_readnbyte((uint8_t)NCTaddr, buff, 2,0) ) 
		{	
			return 0;
		};
		
		tmcpT = (u32) (buff[0]<<8) | buff[1];
		bmeT = (tmcpT>>4) * 625 / 100;
		
		return 1;
}


int uvinit(void)
{
		//return 1;
		buff[0] = (uint8_t) 0b0;//config reg
		buff[1] = (uint8_t) 0b00100000;//low byte
		buff[2] = (uint8_t) 0b0;//high byte
		if( ! I2C_writenbyte((uint8_t)UVaddr, buff, 3,0) ) 
		{
			I2C->CR2 |= I2C_CR2_STOP;//I2C_GenerateSTOP(ENABLE);
			return 0;
		};

		//I2C->CR2 |= I2C_CR2_STOP;
		
		return 1;
}

int uvdata(void)
{
		double e,t;
		int i;
		long tmcpT;
		
		buff[0] = (uint8_t) 0x09;//uva
		if( ! I2C_writenbyte((uint8_t)UVaddr, buff, 1,1) ) 
		{
			I2C_GenerateSTOP(ENABLE);
			return 0;
		};
		
		if (! I2C_readnbyte((uint8_t)UVaddr, buff, 2,1) ) 
		{	
			return 0;
		};
		
		//I2C_GenerateSTOP(ENABLE);
		
		return 1;
}


double mypow(double a,int b) {
		
		//if (b=0) return 0;
		double x=a;
		if (b==1) return a;
		//b--;
		while (b--) 
		{
			x *= a;
		}
		
		return x;
}

int mcpinit(void)
{
		buff[0] = (uint8_t) 0b00011111;
		if( ! I2C_writenbyte((uint8_t)MCPaddr, buff, 2,0) ) 
		{
			I2C->CR2 |= I2C_CR2_STOP;//I2C_GenerateSTOP(ENABLE);
			return 0;
		};
		
		
		return 1;
}

int mcpdata(void)
{
		double e,t;
		int i;
		long tmcpT;
		
		if (! I2C_readnbyte((uint8_t)MCPaddr, buff, 4,0) ) return 0;		
		
		tmcpT = (int32_t) buff[0]<<16 | buff[1]<<8 | buff[2];
		
		e = (double) tmcpT/512; //* 15.625/8000;//в миливольтах
			
		if (e <-5) return 0;	
		if (e >30) return 0; //720gradusov
		
		t=0;

		//e = 20.0;

		if (e>20) 
		{		
			t=t+cKf[0];
			for (i=0;i<6;i++) 
			{
				t=t + (cKf[i+1])*mypow(e,(i+1));
			}
		} else {
			for (i=0;i<((e>0)? 9 : 8);i++) 
			{
				t=t + ((e>0)?cK[i]:cKm[i])*mypow(e,i+1);
			}
		}
		t*=100;
		tmcpT = (long) t + bmeT;
		mcpT = tmcpT;
		//mcpT += bmeT;
		//c = (float)pow(a,b);
		
		return 1;
}


void cifra(u8 num){
	ALLOFF
	
	if (num==0) {
		AON;BON;CON;DON;EON;FON;
	}
	if (num==1) {
		BON;CON;
	}
	if (num==2) {
		AON;BON;GON;EON;DON;
	}
	if (num==3) {
		AON;BON;CON;DON;GON;
	}
	if (num==4) {
		FON;GON;BON;CON;
	}
	if (num==5) {
		AON;FON;GON;CON;DON;
	}
	if (num==6) {
		AON;EON;FON;GON;CON;DON;
	}
	if (num==7) {
		AON;BON;CON;
	}
	if (num==8) {
		AON;BON;CON;GON;DON;EON;FON;
	}
	if (num==9) {
		AON;BON;CON;GON;DON;FON;
	}
	
}
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
void main(void)
{
	//питание - оставляем только нужную периферию!
	CLK->PCKENR1 = CLK_PCKENR1_TIM4+CLK_PCKENR1_TIM2+CLK_PCKENR1_I2C+CLK_PCKENR1_TIM1;
	CLK->PCKENR2 = 0b01111111;

	
	CLK_HSIPrescalerConfig(CLK_PRESCALER_HSIDIV8);//2mgh энергосбережение
	//internal clock
	
	
	//индикатор
	GPIO_Init(GPIOD,GPIO_PIN_2|GPIO_PIN_3|GPIO_PIN_4|GPIO_PIN_5|GPIO_PIN_6,GPIO_MODE_OUT_PP_HIGH_SLOW);
	GPIO_Init(GPIOA,GPIO_PIN_1|GPIO_PIN_2,GPIO_MODE_OUT_PP_HIGH_SLOW);
	GPIO_Init(GPIOC,GPIO_PIN_5|GPIO_PIN_6|GPIO_PIN_7,GPIO_MODE_OUT_PP_HIGH_SLOW);
 
	GPIO_WriteHigh(GPIOC,GPIO_PIN_1);
	GPIO_WriteLow(GPIOA,GPIO_PIN_2);
	
	GPIO_Init(GPIOC,GPIO_PIN_3,GPIO_MODE_OUT_PP_LOW_FAST);//PWM FAN
	GPIO_Init(GPIOA,GPIO_PIN_3,GPIO_MODE_OUT_PP_LOW_FAST);//Spiral


	//ADC кнопки
	GPIO_Init(GPIOC,GPIO_PIN_4,GPIO_MODE_IN_FL_NO_IT);//кнопка!
	ADC1_DeInit();
	ADC1_Init(ADC1_CONVERSIONMODE_SINGLE, ADC1_CHANNEL_2, ADC1_PRESSEL_FCPU_D2, \
            ADC1_EXTTRIG_TIM, DISABLE, ADC1_ALIGN_RIGHT, ADC1_SCHMITTTRIG_CHANNEL2,\
            DISABLE);
	ADC1_Cmd(ENABLE);
	
	/*
	while (1) {
			u16 i;
			ADC1_StartConversion();
			//for(i=0;i<10000;i++);
			//ADC1_StartConversion();
			while( ADC1_GetFlagStatus(ADC1_FLAG_EOC) == RESET);
			ADC1_ClearFlag(ADC1_FLAG_EOC);
			adcval = ADC1_GetConversionValue();
	};
	*/
	
	TIM4_TimeBaseInit(TIM4_PRESCALER_8, 249);
  TIM4_ClearFlag(TIM4_FLAG_UPDATE);
	TIM4_ITConfig(TIM4_IT_UPDATE, ENABLE);
  TIM4->IER |= (uint8_t)TIM4_IT_UPDATE;

	//настройку прерваний надо делать до их включения!
	//надо оба фронта для отслеживания долгого нажатия!
	/* enable interrupts */
	enableInterrupts();

	/* Enable TIM4 */
	TIM4_Cmd(ENABLE);
	
	
	TIM2_TimeBaseInit(TIM2_PRESCALER_8, 249);
  TIM2_ClearFlag(TIM2_FLAG_UPDATE);
	TIM2_ITConfig(TIM2_IT_UPDATE, ENABLE);
  TIM2->IER |= (uint8_t)TIM2_IT_UPDATE;
  
	
	//PWM timer
	TIM1_DeInit();
	TIM1_TimeBaseInit(36000, TIM1_COUNTERMODE_UP, MAXPWM, 0);
	
	TIM1_CCPreloadControl(DISABLE);
	
	TIM1_BDTRConfig(TIM1_OSSISTATE_DISABLE,
                     TIM1_LOCKLEVEL_OFF,
                     0,
                     TIM1_BREAK_DISABLE,
                     TIM1_BREAKPOLARITY_LOW,TIM1_AUTOMATICOUTPUT_DISABLE);
										 
	TIM1_OC1Init(TIM1_OCMODE_PWM2, TIM1_OUTPUTSTATE_DISABLE, TIM1_OUTPUTNSTATE_DISABLE,
               0, TIM1_OCPOLARITY_LOW, TIM1_OCNPOLARITY_HIGH, TIM1_OCIDLESTATE_SET,
               TIM1_OCNIDLESTATE_RESET); 
	/* TIM1 counter enable */
  TIM1_CtrlPWMOutputs(DISABLE); //vse v preryvanii!
	TIM1_Cmd(ENABLE);
	TIM1_ITConfig(TIM1_IT_UPDATE|TIM1_IT_CC1, ENABLE);
	//Delay(10000);
	
	//BEEP_LSICalibrationConfig(LSIMeasurment());
	//BEEP_Cmd(DISABLE);
	//BEEP_Init(BEEP_FREQUENCY_1KHZ);
	//BEEP_Cmd(ENABLE);
	//Delay(1000);
	//BEEP_Cmd(DISABLE);
	Delay(100);

	bmeT=0;
	
	TIM2_Cmd(ENABLE);
	
	//I2C_DeInit();
	I2C_Cmd( ENABLE);
  I2C_Init(I2C_MAX_STANDARD_FREQ, (uint8_t)0xA0, I2C_DUTYCYCLE_2, I2C_ACK_CURR, I2C_ADDMODE_7BIT, 7);
	
	mcpinit();
	//uvinit();
	nctinit();
	
	//kn[4] = KNONE;
	
	//fan=1;
	if (fan==0) {
		ind[0] = 10;//P
		ind[1] = 10;//P
		ind[2] = 10;//P
	} else {
		ind[0] = 11;//F
		ind[1] = 11;//F
		ind[2] = 11;//F
	}
	Delay(3000);
	
	
	/* Infinite loop */
  while (1) {
		
		{
			//аварийная остановка
			u8 i;
			for (i=0;i<4;i++) {
				if (kn[i]==KNTWO) {
					kn[i]=0;
					spiralpower=0;
					temp=0;
					shownumber(999);
					timeshownext=3;
				}
			}
		}
		
		if (kn[1] == KNONE) {
			//меньше скорость фена!!
			kn[1]=0;			
			temp-=10;
			if (temp>1000) temp=0;
		}
		if (kn[1] == KNLONG) {
			//меньше скорость фена!!
			kn[1]=0;			
			temp-=100;
			if (temp>1000) temp=0;
		}
		
		if (kn[2] == KNONE) {
			//меньше скорость фена!!
			kn[2]=0;			
			temp+=10;
			if (temp>500) temp=500;
		}
		if (kn[2] == KNLONG) {
			//меньше скорость фена!!
			kn[2]=0;			
			temp+=100;
			if (temp>500) temp=500;
		}

		
		
		if ((kn[0] == KNONE) || (kn[0] == KNLONG)) {
			//меньше скорость фена!!
			kn[0]=0;			
			speedfan--;
			if (speedfan==0) speedfan=1;
			
			//hKi_Gain -=1;
			
			timeshownext=2;
			showinfo(0);
			
		}
		
		if ((kn[3] == KNONE) || (kn[3] == KNLONG)) {
			//меньше скорость фена!!
			kn[3]=0;			
			speedfan++;
			if (speedfan>4) speedfan=4;
			
			//hKi_Gain +=1;
			
			timeshownext=2;
			showinfo(0);
		}

		if (temp != tempold) {			
			//поменяем скорость мотора!
			timeshownext=2;
			showinfo(1);
			
			tempold = temp;
		}

		if (speedfan != speedfanold) {			
			//поменяем скорость мотора!
			timeshownext=2;
			showinfo(0);
			
			speedfanold = speedfan;
			TIM1->CCR1L = (MAXPWM-4)+(uint8_t)(speedfan);
		}

		if (timeshownext==0) {
			timeshownext= 1;
			
			showinfo(10);
			
			showind++;
			if (showind>=6) showind = 0;			
		}

		/*
		if (kn[0] >= KNONE && 0) {
			kn[0]=0;
			rezhim++;
			if (rezhim>2) rezhim = 0;
			
			tchk[0]=0;
			tchk[1]=0;
			tchk[2]=0;
				
			if (rezhim==0) {
				tchk[1]=1;
				timenct=0;
			}	
		
			if (rezhim==1) {
				tchk[2]=1;
				timemcp =0;
				timenct =0;
			}	
			
			if (rezhim==2) {
				tchk[0]=1;
				ind[0]=10;
				ind[1]=10;
				ind[2]=10;
			}	
		}		
		*/	
		
		
		//if (timenct==0) {
		//	timenct = 200;
			//if (rezhim==0) {
			//	shownumber(bmeT/10);
			//}	
		//}	
		
		//if (rezhim == 2) {
		//	if (timeuv==0) {
		//		//uvdata();
		//	}	
		//	timeuv=200;
		//}	
		
		
		if (timemcp==0)  {
			nctdata();
			
			if (mcpdata()==0){
				//error!!
				mcpT = 999;
			} else mcpT /= 100;
			//получили новые данные, посчитаем новую мощность
			if ((temp==0) || (mcpT > 600)) {
				spiralpower=0;
			} else
				spiralpower = PI_Regulator(temp, mcpT);
				
			
			//shownumber(mcpT);
			timemcp=300;
		}		
		
		
  }
}

#ifdef USE_FULL_ASSERT

/**
  * @brief  Reports the name of the source file and the source line number
  *   where the assert_param error has occurred.
  * @param file: pointer to the source file name
  * @param line: assert_param error line source number
  * @retval : None
  */
void assert_failed(u8* file, u32 line)
{ 
  /* User can add his own implementation to report the file name and line number,
     ex: printf("Wrong parameters value: file %s on line %d\r\n", file, line) */

  /* Infinite loop */
  while (1)
  {
  }
}
#endif


/************************ (C) COPYRIGHT STMicroelectronics *****END OF FILE****/
uint32_t LSIMeasurment(void)
{

  uint32_t lsi_freq_hz = 0x0;
  uint32_t fmaster = 0x0;
  uint16_t ICValue1 = 0x0;
  uint16_t ICValue2 = 0x0;

  /* Get master frequency */
  fmaster = CLK_GetClockFreq();

  /* Enable the LSI measurement: LSI clock connected to timer Input Capture 1 */
  AWU->CSR |= AWU_CSR_MSR;

#if defined (STM8S903) || defined (STM8S103) || defined (STM8S003)
  /* Measure the LSI frequency with TIMER Input Capture 1 */
  
  /* Capture only every 8 events!!! */
  /* Enable capture of TI1 */
	//TIM1_ICInit(TIM1_CHANNEL_1, TIM1_ICPOLARITY_RISING, TIM1_ICSELECTION_DIRECTTI, TIM1_ICPSC_DIV8, 0);
	
	//TI1_Config((uint8_t)TIM1_ICPOLARITY_RISING,
  //             (uint8_t)TIM1_ICSELECTION_DIRECTTI,
  //             (uint8_t)0);
	TIM1->CCER1 &= (uint8_t)(~TIM1_CCER1_CC1E);
  
  /* Select the Input and set the filter */
  TIM1->CCMR1 = (uint8_t)((uint8_t)(TIM1->CCMR1 & (uint8_t)(~(uint8_t)( TIM1_CCMR_CCxS | TIM1_CCMR_ICxF ))) | 
                          (uint8_t)(( (TIM1_ICSELECTION_DIRECTTI)) | ((uint8_t)( 0 << 4))));
	TIM1->CCER1 &= (uint8_t)(~TIM1_CCER1_CC1P);
	TIM1->CCER1 |=  TIM1_CCER1_CC1E;
	
   /* Set the Input Capture Prescaler value */
	//TIM1_SetIC1Prescaler(TIM1_ICPSC_DIV8);
	TIM1->CCMR1 = (uint8_t)((uint8_t)(TIM1->CCMR1 & (uint8_t)(~TIM1_CCMR_ICxPSC)) 
                          | (uint8_t)TIM1_ICPSC_DIV8);
	
  /* Enable TIM1 */
  //TIM1_Cmd(ENABLE);
	TIM1->CR1 |= TIM1_CR1_CEN;
  
  /* wait a capture on cc1 */
  while((TIM1->SR1 & TIM1_FLAG_CC1) != TIM1_FLAG_CC1);
  /* Get CCR1 value*/
  ICValue1 = TIM1_GetCapture1();
  TIM1_ClearFlag(TIM1_FLAG_CC1);
  
  /* wait a capture on cc1 */
  while((TIM1->SR1 & TIM1_FLAG_CC1) != TIM1_FLAG_CC1);
  /* Get CCR1 value*/
  ICValue2 = TIM1_GetCapture1();
  TIM1_ClearFlag(TIM1_FLAG_CC1);
  
  /* Disable IC1 input capture */
  TIM1->CCER1 &= (uint8_t)(~TIM1_CCER1_CC1E);
  /* Disable timer2 */
  TIM1_Cmd(DISABLE);
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

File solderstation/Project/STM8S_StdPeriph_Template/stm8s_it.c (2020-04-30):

/**
  ******************************************************************************
  * @file    stm8s_it.c
  * @author  MCD Application Team
  * @version V2.2.0
  * @date    30-September-2014
  * @brief   Main Interrupt Service Routines.
  *          This file provides template for all peripherals interrupt service 
  *          routine.
   ******************************************************************************
  * @attention
  *
  * <h2><center>&copy; COPYRIGHT 2014 STMicroelectronics</center></h2>
  *
  * Licensed under MCD-ST Liberty SW License Agreement V2, (the "License");
  * You may not use this file except in compliance with the License.
  * You may obtain a copy of the License at:
  *
  *        http://www.st.com/software_license_agreement_liberty_v2
  *
  * Unless required by applicable law or agreed to in writing, software 
  * distributed under the License is distributed on an "AS IS" BASIS, 
  * WITHOUT WARRANTIES OR CONDITIONS OF ANY KIND, either express or implied.
  * See the License for the specific language governing permissions and
  * limitations under the License.
  *
  ******************************************************************************
  */ 

/* Includes ------------------------------------------------------------------*/
#include "stm8s_it.h"

extern uint32_t current_millis;
extern long mcpT;
extern u8 sec,min;
//u16 timesec=999;

/** @addtogroup Template_Project
  * @{
  */

/* Private typedef -----------------------------------------------------------*/
/* Private define ------------------------------------------------------------*/
/* Private macro -------------------------------------------------------------*/
/* Private variables ---------------------------------------------------------*/
/* Private function prototypes -----------------------------------------------*/
/* Private functions ---------------------------------------------------------*/
/* Public functions ----------------------------------------------------------*/

#ifdef _COSMIC_
/**
  * @brief Dummy Interrupt routine
  * @par Parameters:
  * None
  * @retval
  * None
*/
INTERRUPT_HANDLER(NonHandledInterrupt, 25)
{
  /* In order to detect unexpected events during development,
     it is recommended to set a breakpoint on the following instruction.
  */
}
#endif /*_COSMIC_*/

/**
  * @brief TRAP Interrupt routine
  * @param  None
  * @retval None
  */
INTERRUPT_HANDLER_TRAP(TRAP_IRQHandler)
{
  /* In order to detect unexpected events during development,
     it is recommended to set a breakpoint on the following instruction.
  */
}

/**
  * @brief Top Level Interrupt routine.
  * @param  None
  * @retval None
  */
INTERRUPT_HANDLER(TLI_IRQHandler, 0)

{
  /* In order to detect unexpected events during development,
     it is recommended to set a breakpoint on the following instruction.
  */
}

/**
  * @brief Auto Wake Up Interrupt routine.
  * @param  None
  * @retval None
  */
INTERRUPT_HANDLER(AWU_IRQHandler, 1)
{
  /* In order to detect unexpected events during development,
     it is recommended to set a breakpoint on the following instruction.
  */
}

/**
  * @brief Clock Controller Interrupt routine.
  * @param  None
  * @retval None
  */
INTERRUPT_HANDLER(CLK_IRQHandler, 2)
{
  /* In order to detect unexpected events during development,
     it is recommended to set a breakpoint on the following instruction.
  */
}

/**
  * @brief External Interrupt PORTA Interrupt routine.
  * @param  None
  * @retval None
  */
INTERRUPT_HANDLER(EXTI_PORTA_IRQHandler, 3)
{
  /* In order to detect unexpected events during development,
     it is recommended to set a breakpoint on the following instruction.
  */
}

/**
  * @brief External Interrupt PORTB Interrupt routine.
  * @param  None
  * @retval None
  */
INTERRUPT_HANDLER(EXTI_PORTB_IRQHandler, 4)
{
  /* In order to detect unexpected events during development,
     it is recommended to set a breakpoint on the following instruction.
  */
}

/**
  * @brief External Interrupt PORTC Interrupt routine.
  * @param  None
  * @retval None
  */
INTERRUPT_HANDLER(EXTI_PORTC_IRQHandler, 5)
{
  /* In order to detect unexpected events during development,
     it is recommended to set a breakpoint on the following instruction.
  */
}

/**
  * @brief External Interrupt PORTD Interrupt routine.
  * @param  None
  * @retval None
  */
INTERRUPT_HANDLER(EXTI_PORTD_IRQHandler, 6)
{
  /* In order to detect unexpected events during development,
     it is recommended to set a breakpoint on the following instruction.
  */
}

/**
  * @brief External Interrupt PORTE Interrupt routine.
  * @param  None
  * @retval None
  */
INTERRUPT_HANDLER(EXTI_PORTE_IRQHandler, 7)
{
  /* In order to detect unexpected events during development,
     it is recommended to set a breakpoint on the following instruction.
  */
}

#if defined (STM8S903) || defined (STM8AF622x) 
/**
  * @brief External Interrupt PORTF Interrupt routine.
  * @param  None
  * @retval None
  */
 INTERRUPT_HANDLER(EXTI_PORTF_IRQHandler, 8)
 {
  /* In order to detect unexpected events during development,
     it is recommended to set a breakpoint on the following instruction.
  */
 }
#endif /* (STM8S903) || (STM8AF622x) */

#if defined (STM8S208) || defined (STM8AF52Ax)
/**
  * @brief CAN RX Interrupt routine.
  * @param  None
  * @retval None
  */
 INTERRUPT_HANDLER(CAN_RX_IRQHandler, 8)
 {
  /* In order to detect unexpected events during development,
     it is recommended to set a breakpoint on the following instruction.
  */
 }

/**
  * @brief CAN TX Interrupt routine.
  * @param  None
  * @retval None
  */
 INTERRUPT_HANDLER(CAN_TX_IRQHandler, 9)
 {
  /* In order to detect unexpected events during development,
     it is recommended to set a breakpoint on the following instruction.
  */
 }
#endif /* (STM8S208) || (STM8AF52Ax) */

/**
  * @brief SPI Interrupt routine.
  * @param  None
  * @retval None
  */
INTERRUPT_HANDLER(SPI_IRQHandler, 10)
{
  /* In order to detect unexpected events during development,
     it is recommended to set a breakpoint on the following instruction.
  */
}

/**
  * @brief Timer1 Update/Overflow/Trigger/Break Interrupt routine.
  * @param  None
  * @retval None
  */


/**
  * @brief Timer1 Capture/Compare Interrupt routine.
  * @param  None
  * @retval None
  */


#if defined (STM8S903) || defined (STM8AF622x)
/**
  * @brief Timer5 Update/Overflow/Break/Trigger Interrupt routine.
  * @param  None
  * @retval None
  */
 INTERRUPT_HANDLER(TIM5_UPD_OVF_BRK_TRG_IRQHandler, 13)
 {
  /* In order to detect unexpected events during development,
     it is recommended to set a breakpoint on the following instruction.
  */
 }
 
/**
  * @brief Timer5 Capture/Compare Interrupt routine.
  * @param  None
  * @retval None
  */
 INTERRUPT_HANDLER(TIM5_CAP_COM_IRQHandler, 14)
 {
  /* In order to detect unexpected events during development,
     it is recommended to set a breakpoint on the following instruction.
  */
 }
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
